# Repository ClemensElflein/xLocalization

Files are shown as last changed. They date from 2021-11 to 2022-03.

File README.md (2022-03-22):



# xLocalization [inactive]

The xLocalization project aims to provide a simple to use, low cost indoor positioning system for hobbyist use.

# Current State
The PCB works fine. Initial testing with the official decawave firmware showed that the localization works, but is not even close to precise enough for my intended application.
Therefore, this project currently will no longer be worked on. There is currently no code for the ESP8266 available.

# License
<br />This work is licensed under a <a rel="license" href="http://creativecommons.org/licenses/by-nc-sa/4.0/">Creative Commons Attribution-NonCommercial-ShareAlike 4.0 International License</a>.

Feel free to use the design in your projects, but don't try to sell the design or products based on it without getting my consent first.

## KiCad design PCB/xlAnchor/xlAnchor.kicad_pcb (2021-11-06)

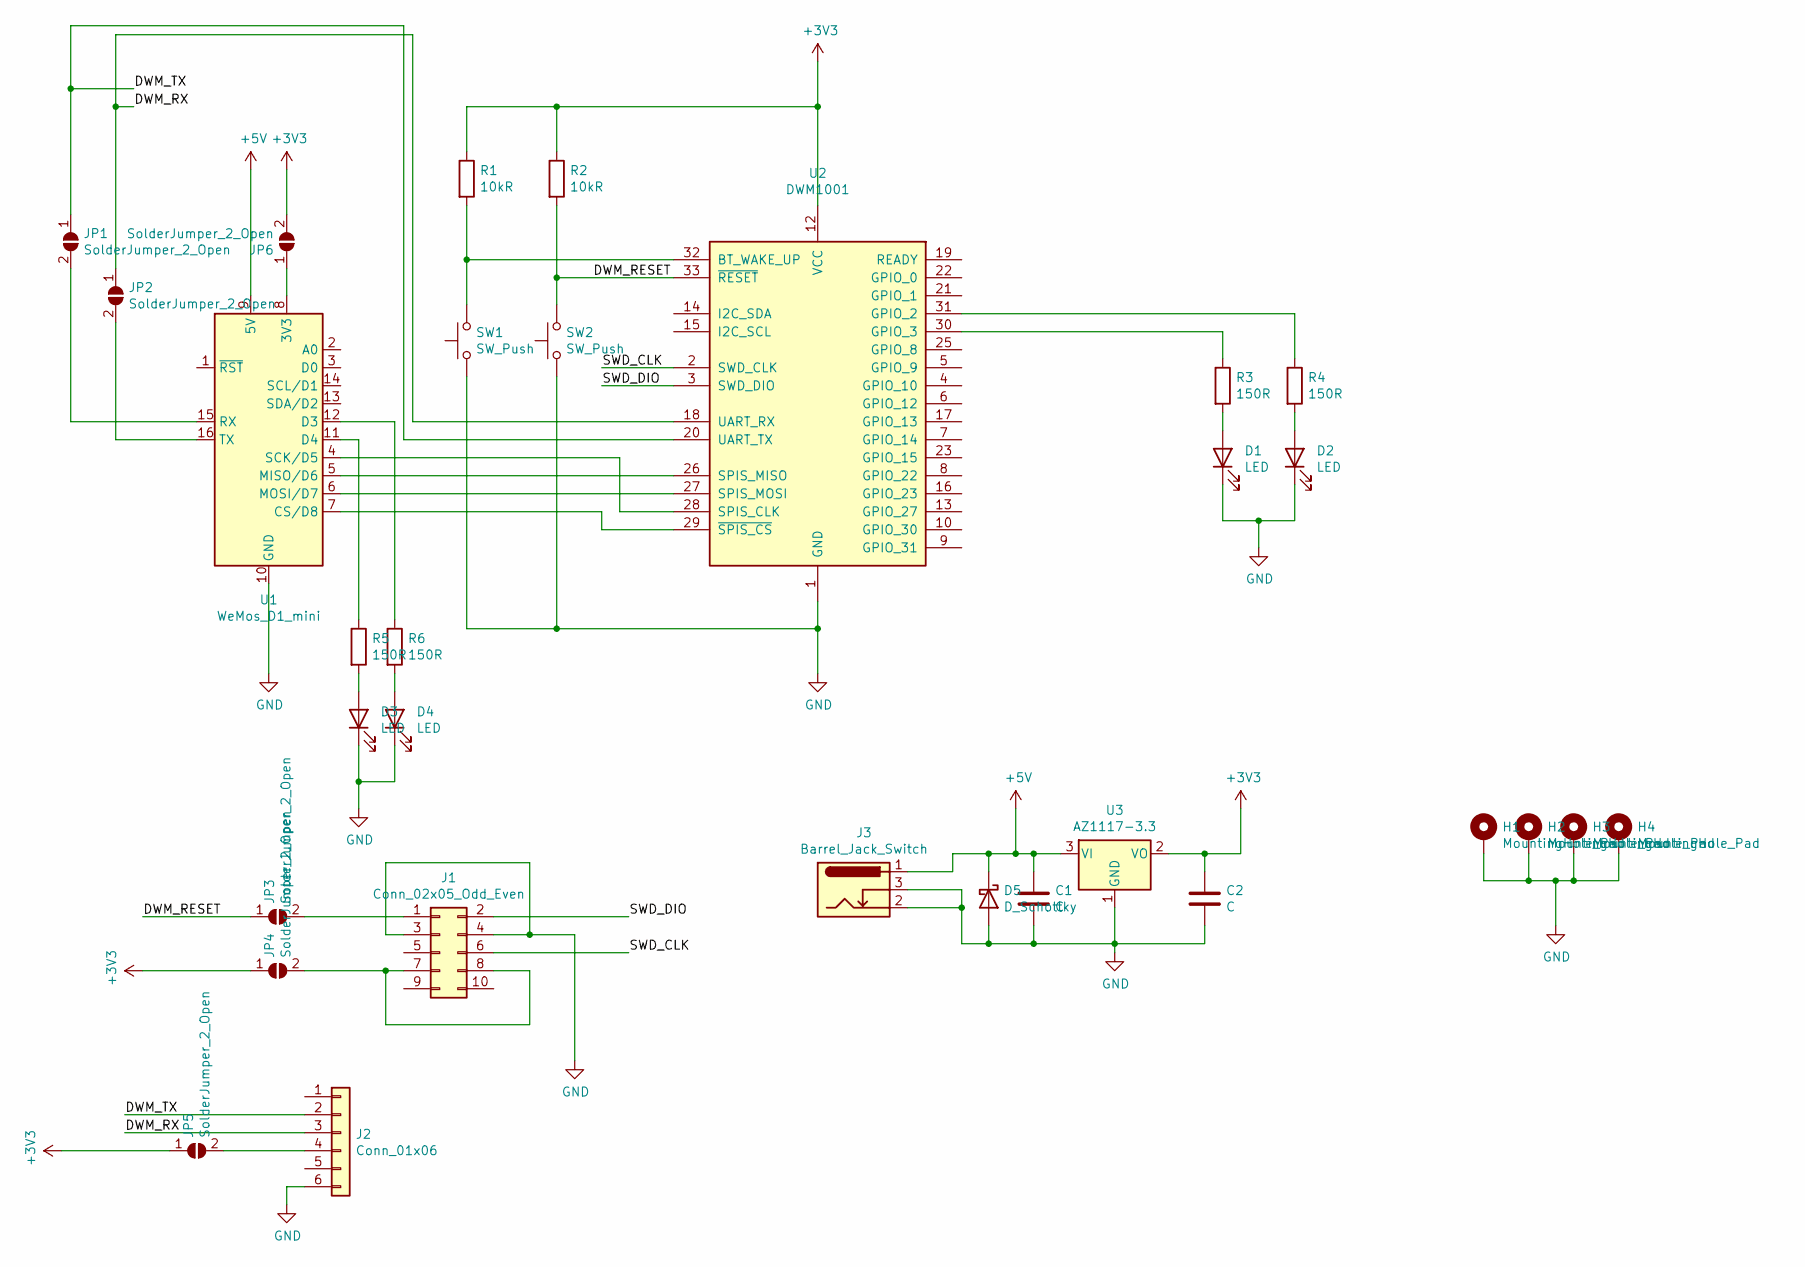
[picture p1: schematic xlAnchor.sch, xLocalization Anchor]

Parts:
C1, C2: C; C_0805_2012Metric
D1, D2, D3, D4: LED; LED_0805_2012Metric_Pad1.15x1.40mm_HandSolder
D5: D_Schottky; D_SOD-123
H1, H2, H3, H4: MountingHole_Pad; MountingHole_3.2mm_M3_DIN965_Pad
J1: Conn_02x05_Odd_Even; PinSocket_2x05_P2.54mm_Vertical
J2: Conn_01x06; PinHeader_1x06_P2.54mm_Vertical
J3: Barrel_Jack_Switch; BarrelJack_Horizontal
JP1, JP2, JP3, JP4, JP5, JP6: SolderJumper_2_Open; SolderJumper-2_P1.3mm_Open_Pad1.0x1.5mm
R1, R2: 10kR; R_0805_2012Metric_Pad1.20x1.40mm_HandSolder
R3, R4, R5, R6: 150R; R_0805_2012Metric_Pad1.20x1.40mm_HandSolder
SW1, SW2: SW_Push; SW_PUSH_6mm
U1: WeMos_D1_mini; WEMOS_D1_mini_light
U2: DWM1001; DecaWave_DWM1001
U3: AZ1117-3.3; SOT-223-3_TabPin2

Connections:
+3V3: C2.1, JP4.1 (A), JP5.1 (A), JP6.2 (B), R1.1, R2.1, U2.12 (VCC), U3.2 (VO)
+5V: C1.1, D5.1 (K), J3.1, U1.9 (5V), U3.3 (VI)
/DWM_RESET: JP3.1 (A), R2.2, SW2.2, U2.33 (~RESET)
/DWM_RX: J2.3, JP2.1 (A), U2.18 (UART_RX)
/DWM_TX: J2.2, JP1.1 (A), U2.20 (UART_TX)
/SWD_CLK: J1.6, U2.2 (SWD_CLK)
/SWD_DIO: J1.2, U2.3 (SWD_DIO)
GND: C1.2, C2.2, D1.1 (K), D2.1 (K), D3.1 (K), D4.1 (K), D5.2 (A), H1.1, H2.1, H3.1, H4.1, J1.3, J1.4, J2.6, J3.2, J3.3, SW1.1, SW2.1, U1.10 (GND), U2.1 (GND), U2.11 (GND), U2.24 (GND), U2.34 (GND), U3.1 (GND)
unnamed: D1.2 (A), R3.2
unnamed: D2.2 (A), R4.2
unnamed: D3.2 (A), R5.2
unnamed: D4.2 (A), R6.2
unnamed: J1.1, JP3.2 (B)
unnamed: J1.7, J1.8, JP4.2 (B)
unnamed: J2.4, JP5.2 (B)
unnamed: JP1.2 (B), U1.15 (RX)
unnamed: JP2.2 (B), U1.16 (TX)
unnamed: JP6.1 (A), U1.8 (3V3)
unnamed: R1.2, SW1.2, U2.32 (BT_WAKE_UP)
unnamed: R3.1, U2.30 (GPIO_3)
unnamed: R4.1, U2.31 (GPIO_2)
unnamed: R5.1, U1.11 (D4)
unnamed: R6.1, U1.12 (D3)
unnamed: U1.4 (SCK/D5), U2.28 (SPIS_CLK)
unnamed: U1.5 (MISO/D6), U2.26 (SPIS_MISO)
unnamed: U1.6 (MOSI/D7), U2.27 (SPIS_MOSI)
unnamed: U1.7 (CS/D8), U2.29 (~SPIS_CS)

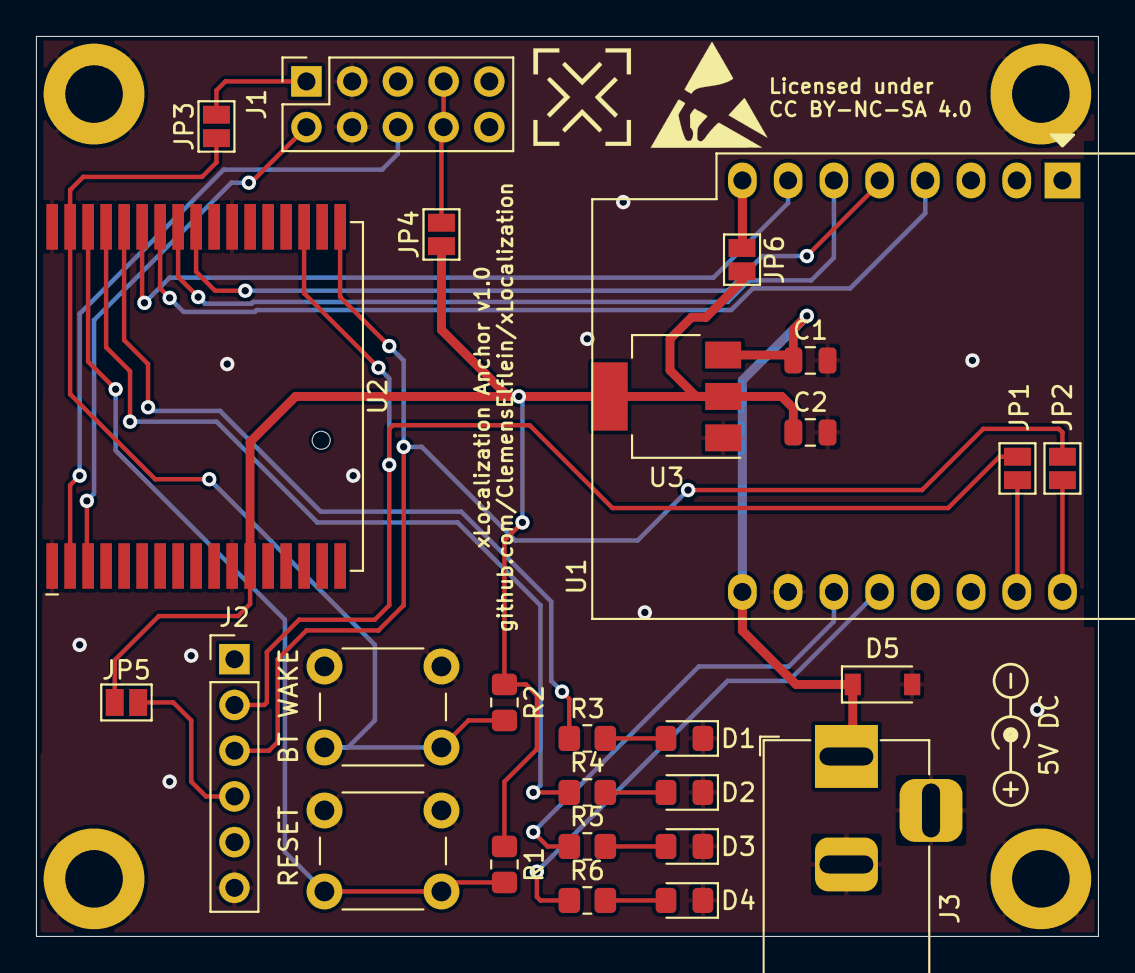
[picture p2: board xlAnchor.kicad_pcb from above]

Board: 2 copper layers, 59.0 x 50.0 mm, 31 parts (0 on the bottom side), 27 nets.

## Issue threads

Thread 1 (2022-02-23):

Is this a working project?

electrooz, 2022-02-23:
I can only see gerber files, no code for this.

Is this project in development, do you have anything functional right now? How does the indoor positioning work?

Thanks.

ClemensElflein, 2022-02-24:
Hi there!
I have a test setup running, but I was not able to document my findings yet, since I'm working on other projects in parallel.

I'm getting indoor positions with 10 Hz and approx 10 cm accuracy.

What accuracy / update rate are you looking for? May I ask which project you are working on?

electrooz, 2022-02-24:
I'm not working on anything yet, I'm collecting data and planning.
10cm accuracy sounds great.

I'm thinking of something on a bigger scale, not quite indoors. A grass cutter for large surfaces. Can you share your setup? Are you working on the ToF principle with something like NRF or ultrasonic modules?

Thanks.

ClemensElflein, 2022-02-24:
That is interesting. I started with these modules for the same thing ;-) But unfortunately the range was not enough for our lawn. We would have needed so many modules, that RTK GPS was simply cheaper and more accurate in the end.

If you are working on a robotic lawn mower, I have great news for you: I am building one myself right now.

Last summer, I have built the prototype (and it already works!!) and during winter I started to develop some PCBs so that anyone can easily convert an off-the-shelf mower. Check out these repos for more info:
https://github.com/ClemensElflein/OpenMower
https://github.com/ClemensElflein/open_mower_ros

The PCBs are already done and I'll have them in the next days. Then I'll post updates and building instructions.

ClemensElflein, 2022-02-24:
As for your initial question: Yes, the modules work with ToF, therefore I expected them to be more accurate. I also noticed that orientation changes have large impact on the computed positions. I'm not really sure why, since it's not based on field strength..

For now, I have installed the official PANS firmware (you can get it here) https://www.decawave.com/dwm1001-dw10001-dev-and-mdek1001-documents-source-code-android-application-firmware-image/ on the modules and I'm using the Android app shipped with their documentation to configure the modules and read the position.

This works great, but accuracy and range is a problem for me. Therefore I currently don't have any NodeMCU code yet.

electrooz, 2022-02-25:
So you ended up using an RTK GPS module for positioning? Interesting. How does it fare with cloudy weather and what module is it? I can tell it's a ublox but if it's something expensive then that's out of my reach.

Robotic lawn mowers aren't the only application I thought about that needs a positioning system.

I may attempt to create my own positioning system for smaller scales with the `nrf24l01`s, got tips?

ClemensElflein, 2022-02-25:
Correct. We are using the Ardusimple RTK module. You can get it here: https://www.ardusimple.com/rtk-starter-kits/. The most basic kit is 211 Euros. Maybe there is also another breakout board available, but the module itself seems to be quite expensive. Therefore I think that the price is fair.

We are using one board for positioning in the robot and another one as base station. You can however stream the RTK data from the internet. Then one kit will be enough.

I did not notice any issues with weather. It's very stable.

With the NR24 you'd use the field strength to do positioning I guess. I haven't tried it and I don't like this approach, since obstacles in the LOS will greatly influence the measured positions.

electrooz, 2022-02-26:
Thank you. I only found ublox RTK chips so far but they're out of reach for me, the only affordable one would be the NEO-6M which isn't nearly as precise as it needs to be.

In theory, based on my brainstorming, a neural network could be trained to cancel out any large oscillations of the position, as well as using other transceivers that don't have obstacles.

Closed 2022-02-27.

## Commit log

2021-11-05 added anchor schematic and pcb
    [xlAnchor.kicad_pcb, xlAnchor.sch]
2021-11-06 ordered first batch of PCBs
    [xlAnchor-B_Cu.gbr, xlAnchor-B_Mask.gbr, xlAnchor-B_Paste.gbr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]

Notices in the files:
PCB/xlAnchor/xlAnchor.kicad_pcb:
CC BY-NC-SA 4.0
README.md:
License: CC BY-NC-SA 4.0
